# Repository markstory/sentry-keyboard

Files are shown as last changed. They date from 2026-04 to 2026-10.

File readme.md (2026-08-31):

# sentry-keyboard

A reverse engineered PCB for the keyboard that Sentry gave as holiday gift in 2024.

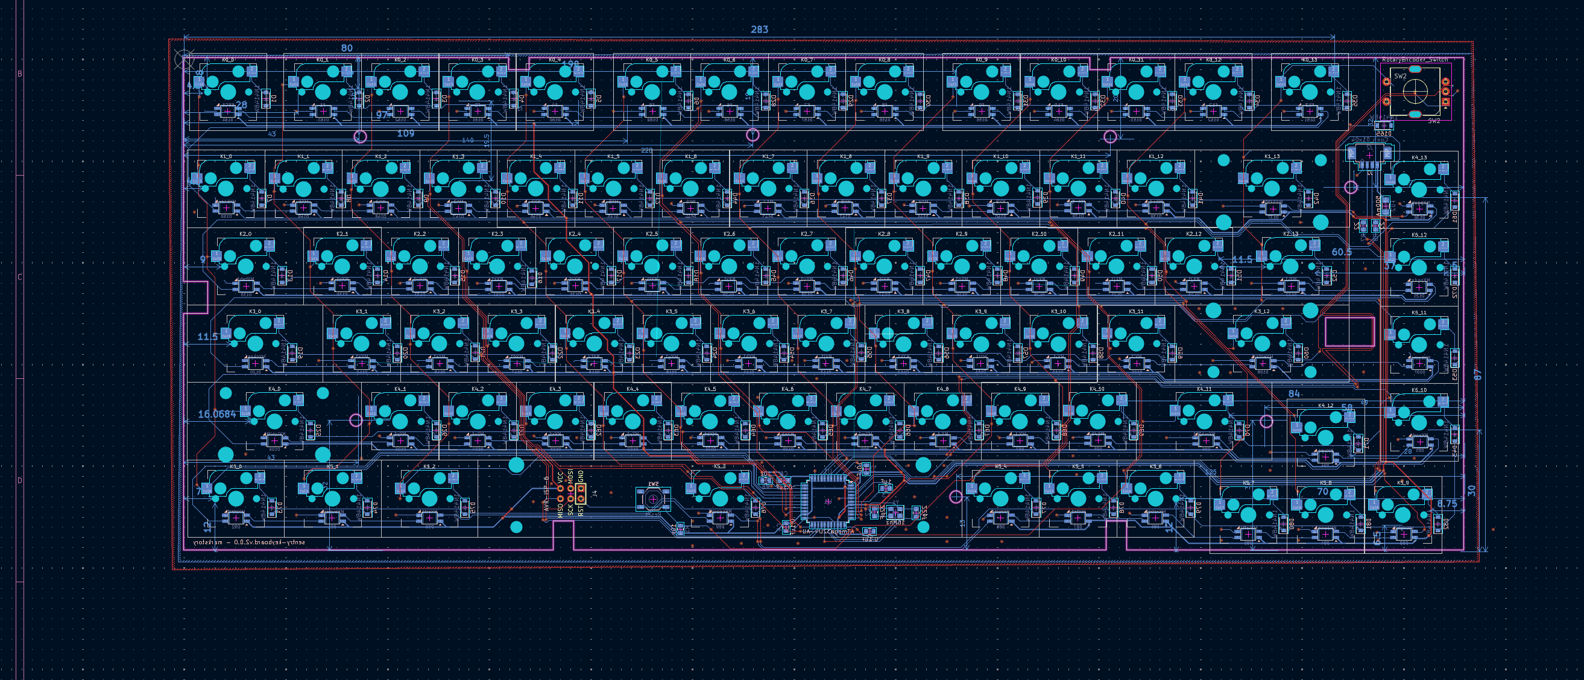
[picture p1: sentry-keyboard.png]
pcb screenshot


## Features

- Per key RGB LEDs
- Rotary encoder with switch
- USB host interface connection through picoblade connector.
- Programmable keymap with QMK

## Building the Firmware

The `firmware` directory of this repostiory contains only the files specific
to this keyboards firmware, and does not include all of QMK. To build firmware you
need to have a copy of QMK (lets assume it is at `~/code/qmk)`:

```bash
cp -R firmware/* ~/code/qmk/keyboards/sentry-keyboard
cd ~/code/qmk
qmk compile -kb sentry-keyboard -km default
```

This will compile a `.hex` file that you can flash onto your keyboard

```bash
qmk flash -kb sentry-keyboard
```

Brand new micro controller chips may have not have the bootloader initialized, 
and you'll need to erase the chip first:

```bash
dfu-programmer atmega32u4 erase
```

Once the chip has been erased you can flash the firmware on.

## License

Both the PCB design and firmware are provided under the MIT License

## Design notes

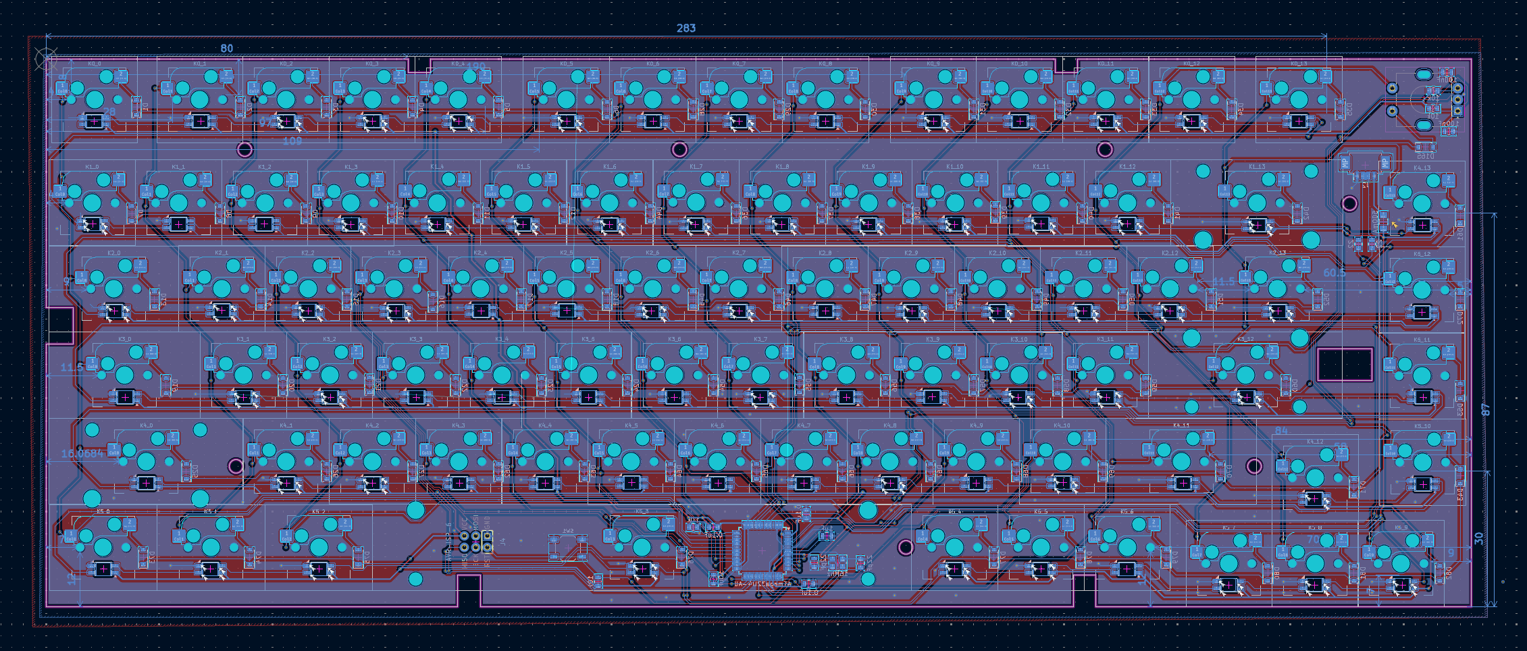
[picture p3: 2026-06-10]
board pcb with fills.png

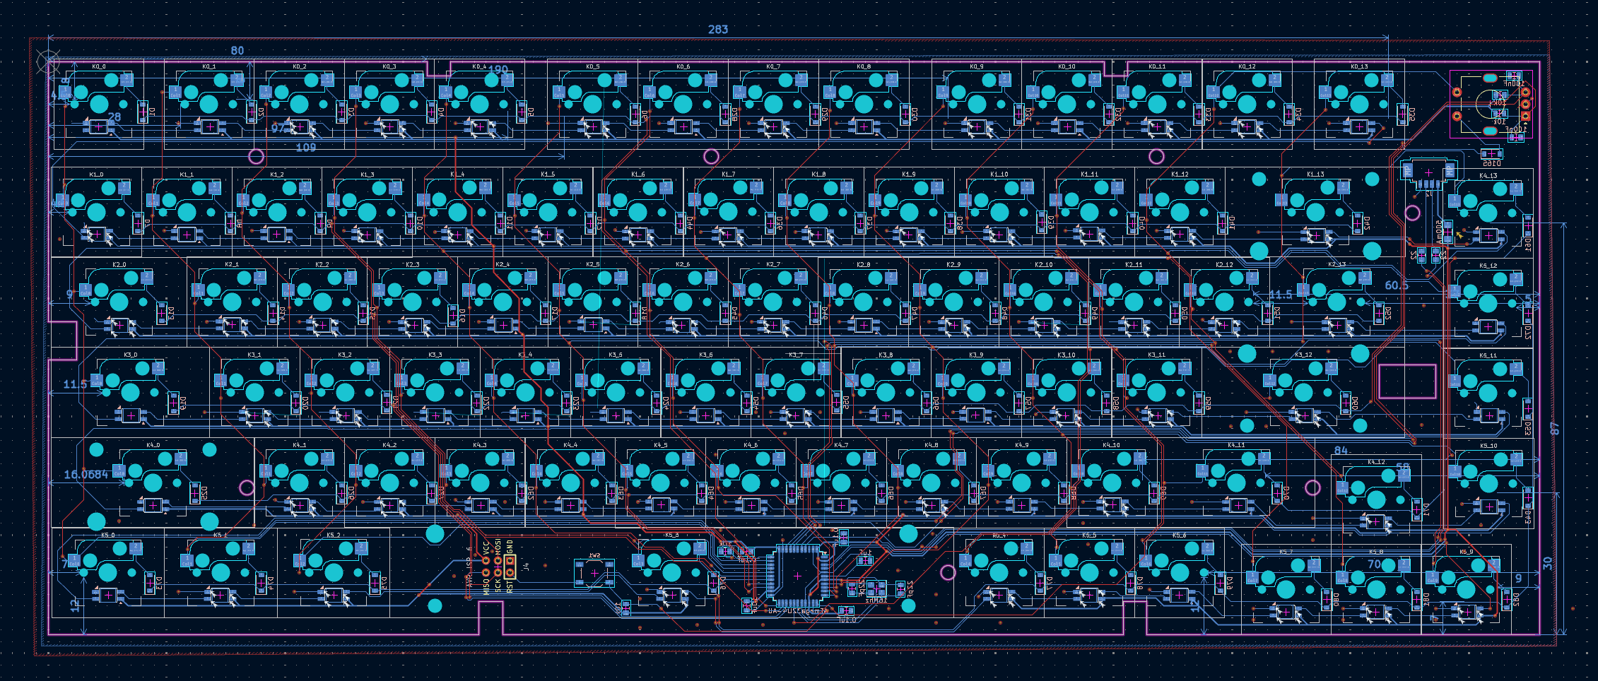
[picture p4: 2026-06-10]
board pcb no fills.png

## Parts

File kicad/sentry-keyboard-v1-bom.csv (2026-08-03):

Id | Designator | Footprint | Quantity | Designation | Supplier and ref
1 | J4 | Reset_Pretty-Mask | 1 | AVR-ISP-6
2 | SW2 | RotaryEncoder_EC11 | 1 | RotaryEncoder_Switch
3 | D62,D77,D46,D66,D32,D27,D79,D43,D65,D49,D42,D165,D64,D8,D61,D73,D81,D41,D69,D50,D1,D52,D34,D37,D14,D58,D76,D21,D45,D51,D31,D68,D2,D25,D10,D67,D30,D35,D23,D38,D6,D47,D9,D15,D57,D53,D59,D72,D11,D13,D12,D54,D80,D60,D28,D74,D16,D56,D17,D22,D33,D5,D24,D26,D48,D4,D44,D63,D3,D70,D40,D36,D78,D39,D20,D82,D7,D71,D18,D55,D19,D29,D75 | D_SOD-123 | 83 | 1N4148W
4 | D160,D126,D150,D96,D119,D147,D87,D109,D152,D105,D146,D110,D133,D85,D159,D88,D162,D90,D144,D134,D138,D84,D129,D132,D153,D83,D135,D145,D89,D141,D118,D108,D91,D104,D113,D137,D155,D98,D128,D157,D94,D151,D140,D107,D103,D149,D131,D114,D102,D148,D122,D116,D100,D115,D95,D86,D130,D111,D156,D120,D123,D93,D158,D117,D136,D106,D112,D161,D92,D101,D125,D164,D121,D139,D99,D124,D154,D143,D127,D142,D163,D97 | SK6812-MINI-E | 82 | SK6812
5 | C4,C6,C5 | C_0805_2012Metric | 3 | 0.1uF
6 | C7 | C_0805_2012Metric | 1 | 10uF
7 | MXr1 | MX-Hotswap-1U | 1 | K2_4
8 | MXx1 | MX-Hotswap-1U | 1 | K4_2
9 | MXlshift1 | MX-Hotswap-2.25U | 1 | K4_0
10 | MXend1 | MX-Hotswap-1U | 1 | K5_10
11 | MXspace1 | MX-Hotswap-6.25U-ReversedStabilizers | 1 | K5_3
12 | MXrshift1 | MX-Hotswap-1.75U | 1 | K4_11
13 | MX;1 | MX-Hotswap-1U | 1 | K3_10
14 | MX.1 | MX-Hotswap-1U | 1 | K4_9
15 | MXh1 | MX-Hotswap-1U | 1 | K3_6
16 | R1,R8 | R_0805_2012Metric | 2 | 10k
17 | C1,C2 | C_0805_2012Metric | 2 | 22pF
18 | C3 | C_0805_2012Metric | 1 | 1uF
19 | MXq1 | MX-Hotswap-1U | 1 | K2_1
20 | MX1 | MX-Hotswap-1U | 1 | K1_1
21 | MX\1 | MX-Hotswap-1.5U | 1 | K2_13
22 | MXbksp1 | MX-Hotswap-2U | 1 | K1_13
23 | MXa1 | MX-Hotswap-1U | 1 | K3_1
24 | MXb1 | MX-Hotswap-1U | 1 | K4_5
25 | MXj1 | MX-Hotswap-1U | 1 | K3_7
26 | SW1 | SW_SPST_TL3342 | 1 | Reset
27 | MX0 | MX-Hotswap-1U | 1 | K1_10
28 | F9 | MX-Hotswap-1U | 1 | K0_9
29 | MXhome1 | MX-Hotswap-1U | 1 | K5_11
30 | MXv1 | MX-Hotswap-1U | 1 | K4_4
31 | MXalt1 | MX-Hotswap-1.25U | 1 | K5_2
32 | MX4 | MX-Hotswap-1U | 1 | K1_4
33 | MXn1 | MX-Hotswap-1U | 1 | K4_6
34 | MX/1 | MX-Hotswap-1U | 1 | K4_10
35 | MXright1 | MX-Hotswap-1U | 1 | K5_9
36 | MXw1 | MX-Hotswap-1U | 1 | K2_2
37 | MXtilde1 | MX-Hotswap-1U | 1 | K1_0
38 | MXleft1 | MX-Hotswap-1U | 1 | K5_7
39 | U1 | TQFP-44_10x10mm_P0.8mm | 1 | ATmega32U4-AU
40 | F5 | MX-Hotswap-1U | 1 | K0_5
41 | MX5 | MX-Hotswap-1U | 1 | K1_5
42 | MXralt1 | MX-Hotswap-1U | 1 | K5_4
43 | MXup1 | MX-Hotswap-1U | 1 | K4_12
44 | MX3 | MX-Hotswap-1U | 1 | K1_3
45 | MXu1 | MX-Hotswap-1U | 1 | K2_7
46 | MXd1 | MX-Hotswap-1U | 1 | K3_3
47 | MXk1 | MX-Hotswap-1U | 1 | K3_8
48 | F7 | MX-Hotswap-1U | 1 | K0_7
49 | MXi1 | MX-Hotswap-1U | 1 | K2_8
50 | MXpgdn1 | MX-Hotswap-1U | 1 | K5_12
51 | F2 | MX-Hotswap-1U | 1 | K0_2
52 | MXpgup1 | MX-Hotswap-1U | 1 | K4_13
53 | F3 | MX-Hotswap-1U | 1 | K0_3
54 | R7,R6 | R_0805_2012Metric | 2 | 22
55 | MXg1 | MX-Hotswap-1U | 1 | K3_5
56 | MX2 | MX-Hotswap-1U | 1 | K1_2
57 | MXz1 | MX-Hotswap-1U | 1 | K4_1
58 | MXt1 | MX-Hotswap-1U | 1 | K2_5
59 | J2 | Molex_PicoBlade_53261-0471_1x04-1MP_P1.25mm_Horizontal | 1 | Conn_01x04
60 | MX'1 | MX-Hotswap-1U | 1 | K3_11
61 | F4 | MX-Hotswap-1U | 1 | K0_4
62 | F10 | MX-Hotswap-1U | 1 | K0_10
63 | MXrctrl1 | MX-Hotswap-1U | 1 | K5_6
64 | FU2 | Fuse_1206_3216Metric_Pad1.42x1.75mm_HandSolder | 1 | 500mA
65 | MXs1 | MX-Hotswap-1U | 1 | K3_2
66 | F12 | MX-Hotswap-1U | 1 | K0_12
67 | MX-1 | MX-Hotswap-1U | 1 | K1_11
68 | MX[1 | MX-Hotswap-1U | 1 | K2_11
69 | F6 | MX-Hotswap-1U | 1 | K0_6
70 | MXdown1 | MX-Hotswap-1U | 1 | K5_8
71 | MXl1 | MX-Hotswap-1U | 1 | K3_9
72 | F8 | MX-Hotswap-1U | 1 | K0_8
73 | MXfn1 | MX-Hotswap-1U | 1 | K5_5
74 | MX,1 | MX-Hotswap-1U | 1 | K4_8
75 | F11 | MX-Hotswap-1U | 1 | K0_11
76 | MXe1 | MX-Hotswap-1U | 1 | K2_3
77 | MXctrl1 | MX-Hotswap-1.25U | 1 | K5_0
78 | F1 | MX-Hotswap-1U | 1 | K0_1
79 | MXf2 | MX-Hotswap-1U | 1 | K3_4
80 | MXm1 | MX-Hotswap-1U | 1 | K4_7
81 | MX]1 | MX-Hotswap-1U | 1 | K2_12
82 | MXenter1 | MX-Hotswap-2.25U-ReversedStabilizers | 1 | K3_12
83 | MX+1 | MX-Hotswap-1U | 1 | K1_12
84 | MX9 | MX-Hotswap-1U | 1 | K1_9
85 | MXtab1 | MX-Hotswap-1.5U | 1 | K2_0
86 | MXy1 | MX-Hotswap-1U | 1 | K2_6
87 | MX8 | MX-Hotswap-1U | 1 | K1_8
88 | MXcaps1 | MX-Hotswap-1.75U | 1 | K3_0
89 | Y1 | Crystal_SMD_3225-4Pin_3.2x2.5mm | 1 | 16Mhz
90 | MXp1 | MX-Hotswap-1U | 1 | K2_10
91 | MXo1 | MX-Hotswap-1U | 1 | K2_9
92 | F13 | MX-Hotswap-1U | 1 | K0_13
93 | MXc1 | MX-Hotswap-1U | 1 | K4_3
94 | MX6 | MX-Hotswap-1U | 1 | K1_6
95 | MX7 | MX-Hotswap-1U | 1 | K1_7
96 | MXsuper1 | MX-Hotswap-1.25U | 1 | K5_1
97 | ESC1 | MX-Hotswap-1U | 1 | K0_0

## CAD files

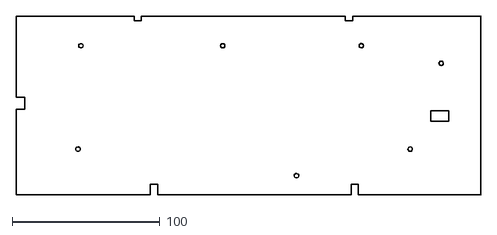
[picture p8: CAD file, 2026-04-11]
board outline.dxf
315.0 x 121.0

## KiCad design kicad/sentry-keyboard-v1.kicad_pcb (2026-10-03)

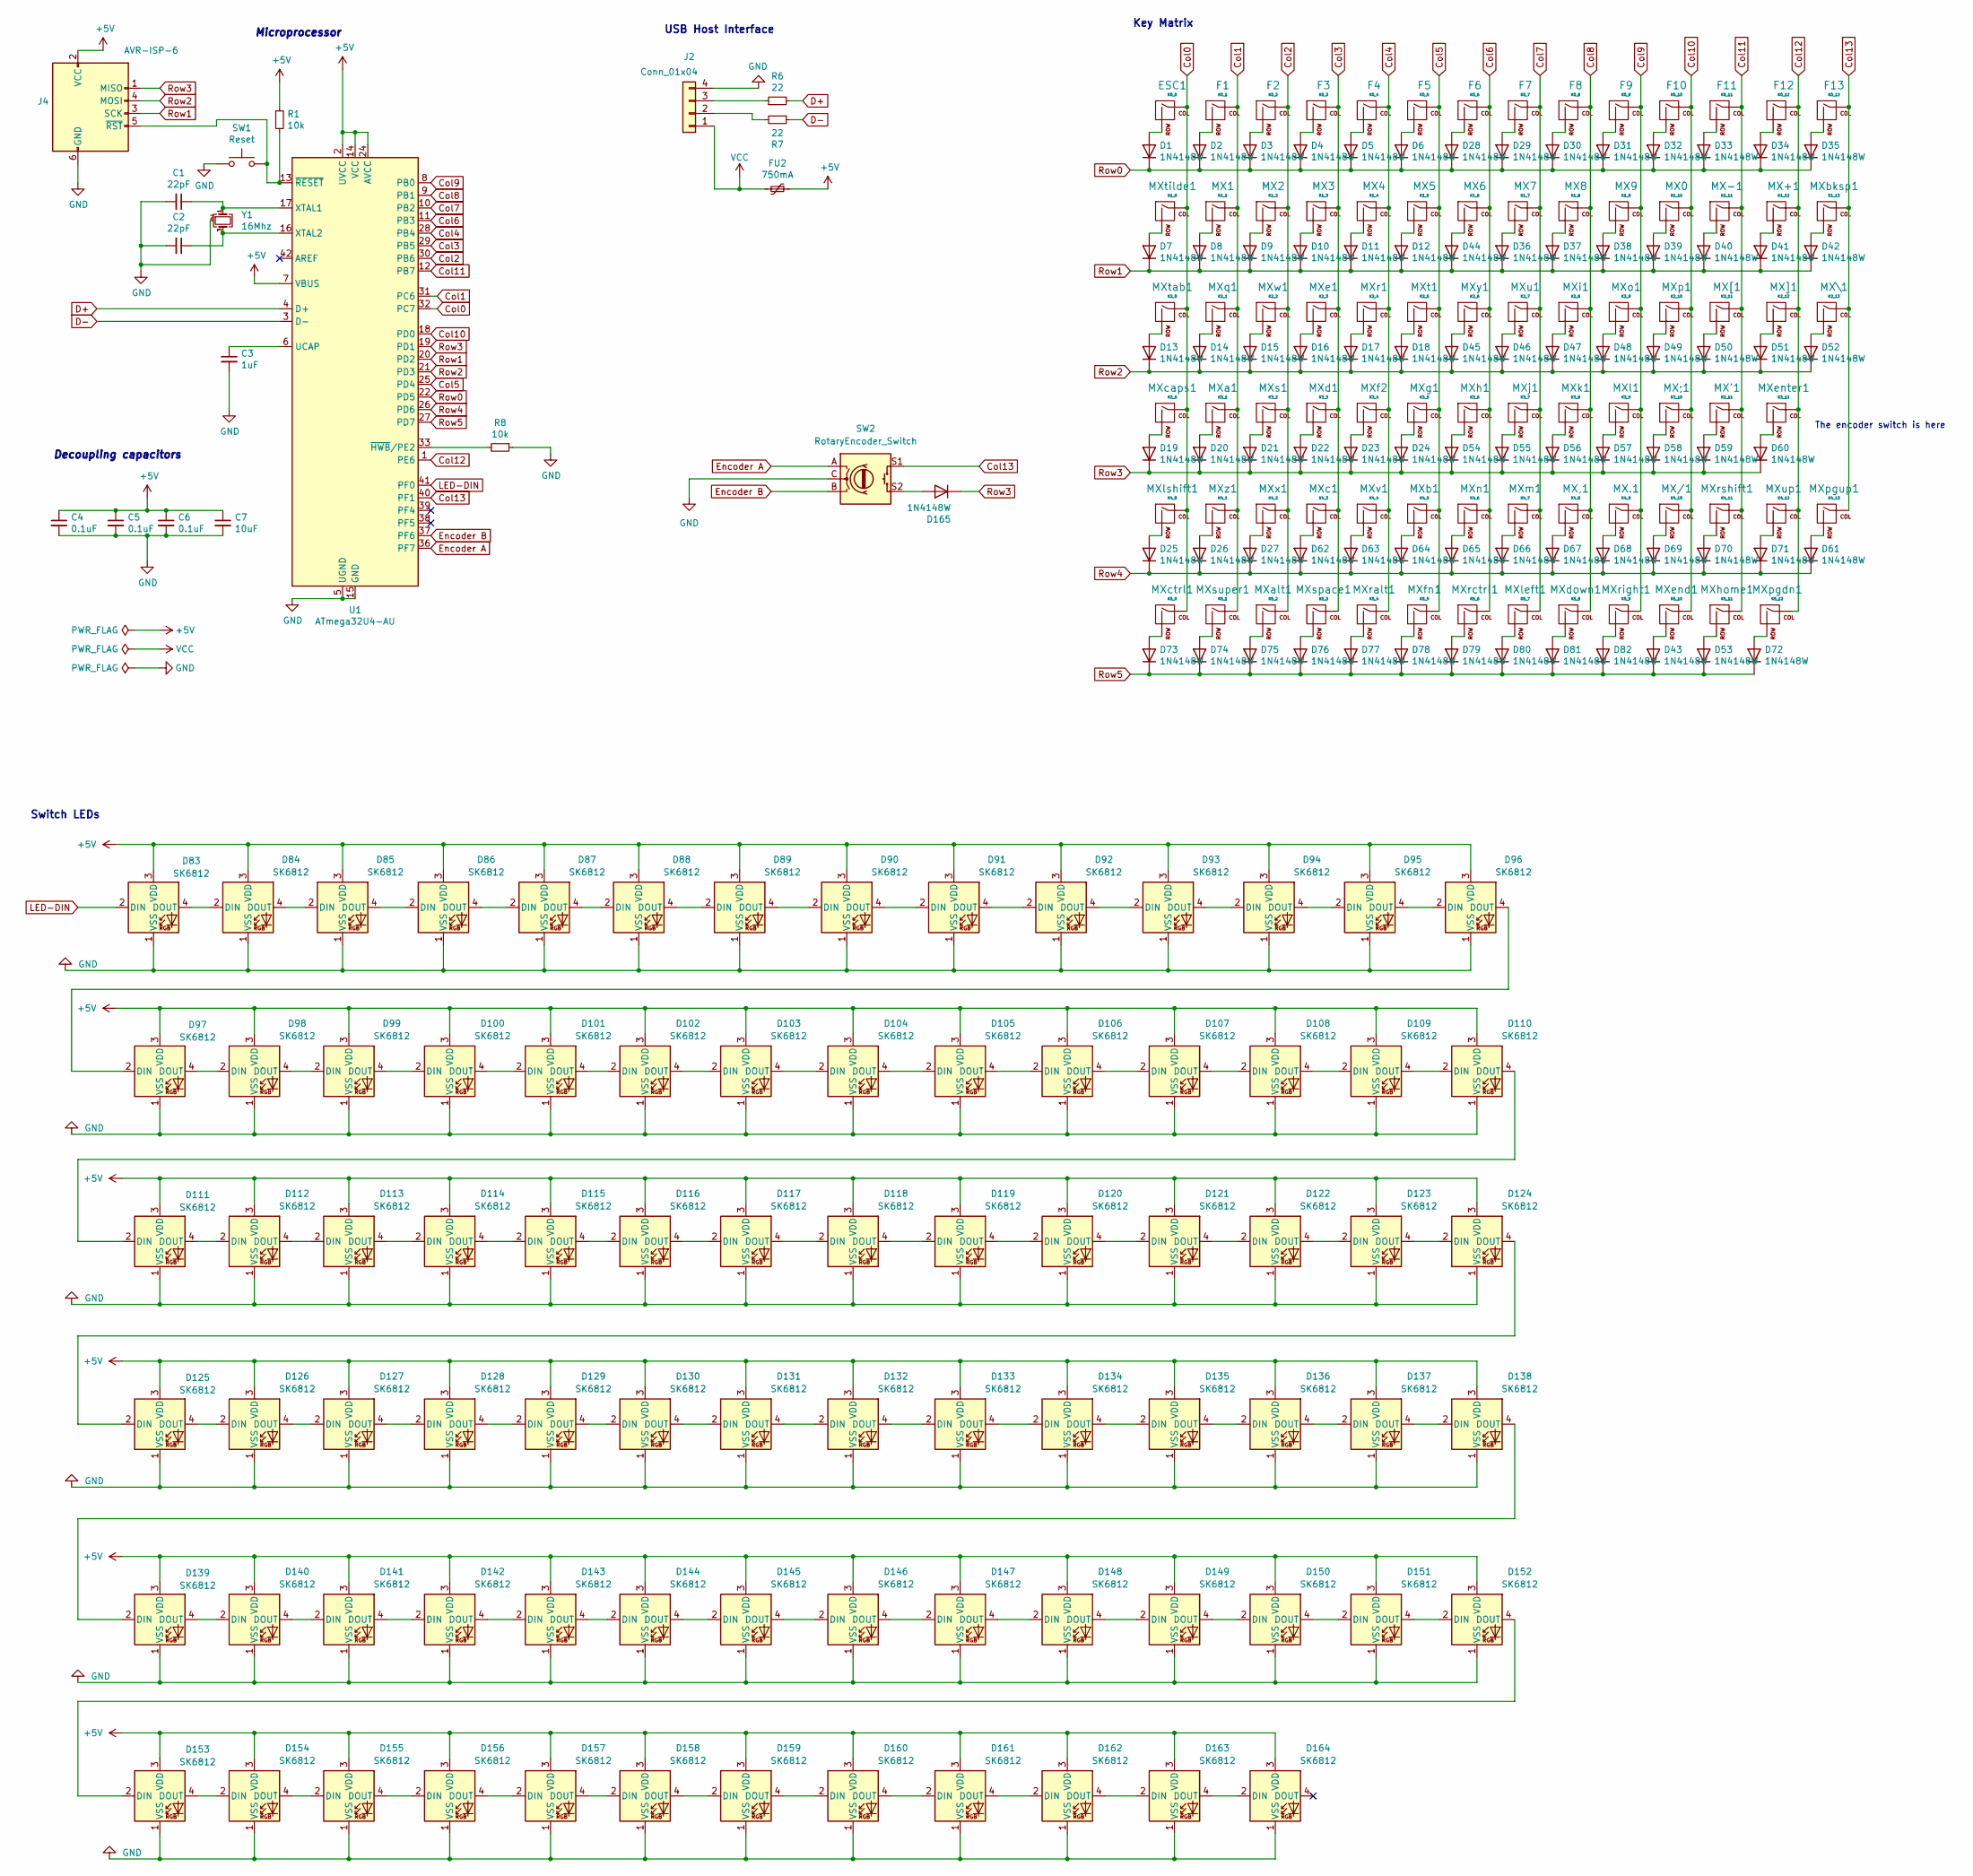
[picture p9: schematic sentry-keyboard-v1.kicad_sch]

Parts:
C1, C2: 22pF; C_0805_2012Metric
C3: 1uF; C_0805_2012Metric
C4, C5, C6: 0.1uF; C_0805_2012Metric
C7: 10uF; C_0805_2012Metric
D1, D2, D3, D4, D5, D6, D7, D8, D9, D10, D11, D12, D13, D14, D15, D16, D17, D18, D19, D20, D21, D22, D23, D24, D25, D26, D27, D28, D29, D30, D31, D32, D33, D34, D35, D36, D37, D38, D39, D40, D41, D42, D43, D44, D45, D46, D47, D48, D49, D50, D51, D52, D53, D54, D55, D56, D57, D58, D59, D60, D61, D62, D63, D64, D65, D66, D67, D68, D69, D70, D71, D72, D73, D74, D75, D76, D77, D78, D79, D80, D81, D82, D165: 1N4148W; D_SOD-123
D83, D84, D85, D86, D87, D88, D89, D90, D91, D92, D93, D94, D95, D96, D97, D98, D99, D100, D101, D102, D103, D104, D105, D106, D107, D108, D109, D110, D111, D112, D113, D114, D115, D116, D117, D118, D119, D120, D121, D122, D123, D124, D125, D126, D127, D128, D129, D130, D131, D132, D133, D134, D135, D136, D137, D138, D139, D140, D141, D142, D143, D144, D145, D146, D147, D148, D149, D150, D151, D152, D153, D154, D155, D156, D157, D158, D159, D160, D161, D162, D163, D164: SK6812; SK6812-MINI-E
ESC1: K0_0; MX-Hotswap-1U
F1: K0_1; MX-Hotswap-1U
F2: K0_2; MX-Hotswap-1U
F3: K0_3; MX-Hotswap-1U
F4: K0_4; MX-Hotswap-1U
F5: K0_5; MX-Hotswap-1U
F6: K0_6; MX-Hotswap-1U
F7: K0_7; MX-Hotswap-1U
F8: K0_8; MX-Hotswap-1U
F9: K0_9; MX-Hotswap-1U
F10: K0_10; MX-Hotswap-1U
F11: K0_11; MX-Hotswap-1U
F12: K0_12; MX-Hotswap-1U
F13: K0_13; MX-Hotswap-1U
FU2: 750mA; Fuse_1206_3216Metric_Pad1.42x1.75mm_HandSolder
J2: Conn_01x04; Molex_PicoBlade_53261-0471_1x04-1MP_P1.25mm_Horizontal
J4: AVR-ISP-6; Reset_Pretty-Mask
MX0: K1_10; MX-Hotswap-1U
MX1: K1_1; MX-Hotswap-1U
MX2: K1_2; MX-Hotswap-1U
MX3: K1_3; MX-Hotswap-1U
MX4: K1_4; MX-Hotswap-1U
MX5: K1_5; MX-Hotswap-1U
MX6: K1_6; MX-Hotswap-1U
MX7: K1_7; MX-Hotswap-1U
MX8: K1_8; MX-Hotswap-1U
MX9: K1_9; MX-Hotswap-1U
MX'1: K3_11; MX-Hotswap-1U
MX+1: K1_12; MX-Hotswap-1U
MX,1: K4_8; MX-Hotswap-1U
MX-1: K1_11; MX-Hotswap-1U
MX.1: K4_9; MX-Hotswap-1U
MX/1: K4_10; MX-Hotswap-1U
MX;1: K3_10; MX-Hotswap-1U
MX[1: K2_11; MX-Hotswap-1U
MX\1: K2_13; MX-Hotswap-1.5U
MX]1: K2_12; MX-Hotswap-1U
MXa1: K3_1; MX-Hotswap-1U
MXalt1: K5_2; MX-Hotswap-1.25U
MXb1: K4_5; MX-Hotswap-1U
MXbksp1: K1_13; MX-Hotswap-2U
MXc1: K4_3; MX-Hotswap-1U
MXcaps1: K3_0; MX-Hotswap-1.75U
MXctrl1: K5_0; MX-Hotswap-1.25U
MXd1: K3_3; MX-Hotswap-1U
MXdown1: K5_8; MX-Hotswap-1U
MXe1: K2_3; MX-Hotswap-1U
MXend1: K5_10; MX-Hotswap-1U
MXenter1: K3_12; MX-Hotswap-2.25U-ReversedStabilizers
MXf2: K3_4; MX-Hotswap-1U
MXfn1: K5_5; MX-Hotswap-1U
MXg1: K3_5; MX-Hotswap-1U
MXh1: K3_6; MX-Hotswap-1U
MXhome1: K5_11; MX-Hotswap-1U
MXi1: K2_8; MX-Hotswap-1U
MXj1: K3_7; MX-Hotswap-1U
MXk1: K3_8; MX-Hotswap-1U
MXl1: K3_9; MX-Hotswap-1U
MXleft1: K5_7; MX-Hotswap-1U
MXlshift1: K4_0; MX-Hotswap-2.25U
MXm1: K4_7; MX-Hotswap-1U
MXn1: K4_6; MX-Hotswap-1U
MXo1: K2_9; MX-Hotswap-1U
MXp1: K2_10; MX-Hotswap-1U
MXpgdn1: K5_12; MX-Hotswap-1U
MXpgup1: K4_13; MX-Hotswap-1U
MXq1: K2_1; MX-Hotswap-1U
MXr1: K2_4; MX-Hotswap-1U
MXralt1: K5_4; MX-Hotswap-1U
MXrctrl1: K5_6; MX-Hotswap-1U
MXright1: K5_9; MX-Hotswap-1U
MXrshift1: K4_11; MX-Hotswap-1.75U
MXs1: K3_2; MX-Hotswap-1U
MXspace1: K5_3; MX-Hotswap-6.25U-ReversedStabilizers
MXsuper1: K5_1; MX-Hotswap-1.25U
MXt1: K2_5; MX-Hotswap-1U
MXtab1: K2_0; MX-Hotswap-1.5U
MXtilde1: K1_0; MX-Hotswap-1U
MXu1: K2_7; MX-Hotswap-1U
MXup1: K4_12; MX-Hotswap-1U
MXv1: K4_4; MX-Hotswap-1U
MXw1: K2_2; MX-Hotswap-1U
MXx1: K4_2; MX-Hotswap-1U
MXy1: K2_6; MX-Hotswap-1U
MXz1: K4_1; MX-Hotswap-1U
R1, R8: 10k; R_0805_2012Metric
R6, R7: 22; R_0805_2012Metric
SW1: Reset; SW_SPST_TL3342
SW2: RotaryEncoder_Switch; RotaryEncoder_EC11
U1: ATmega32U4-AU; TQFP-44_10x10mm_P0.8mm
Y1: 16Mhz; Crystal_SMD_3225-4Pin_3.2x2.5mm

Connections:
+5V: C4.1, C5.1, C6.1, C7.1, D83.3 (VDD), D84.3 (VDD), D85.3 (VDD), D86.3 (VDD), D87.3 (VDD), D88.3 (VDD), D89.3 (VDD), D90.3 (VDD), D91.3 (VDD), D92.3 (VDD), D93.3 (VDD), D94.3 (VDD), D95.3 (VDD), D96.3 (VDD), D97.3 (VDD), D98.3 (VDD), D99.3 (VDD), D100.3 (VDD), D101.3 (VDD), D102.3 (VDD), D103.3 (VDD), D104.3 (VDD), D105.3 (VDD), D106.3 (VDD), D107.3 (VDD), D108.3 (VDD), D109.3 (VDD), D110.3 (VDD), D111.3 (VDD), D112.3 (VDD), D113.3 (VDD), D114.3 (VDD), D115.3 (VDD), D116.3 (VDD), D117.3 (VDD), D118.3 (VDD), D119.3 (VDD), D120.3 (VDD), D121.3 (VDD), D122.3 (VDD), D123.3 (VDD), D124.3 (VDD), D125.3 (VDD), D126.3 (VDD), D127.3 (VDD), D128.3 (VDD), D129.3 (VDD), D130.3 (VDD), D131.3 (VDD), D132.3 (VDD), D133.3 (VDD), D134.3 (VDD), D135.3 (VDD), D136.3 (VDD), D137.3 (VDD), D138.3 (VDD), D139.3 (VDD), D140.3 (VDD), D141.3 (VDD), D142.3 (VDD), D143.3 (VDD), D144.3 (VDD), D145.3 (VDD), D146.3 (VDD), D147.3 (VDD), D148.3 (VDD), D149.3 (VDD), D150.3 (VDD), D151.3 (VDD), D152.3 (VDD), D153.3 (VDD), D154.3 (VDD), D155.3 (VDD), D156.3 (VDD), D157.3 (VDD), D158.3 (VDD), D159.3 (VDD), D160.3 (VDD), D161.3 (VDD), D162.3 (VDD), D163.3 (VDD), D164.3 (VDD), FU2.1, J4.2 (VCC), R1.1, U1.2 (UVCC), U1.7 (VBUS), U1.14 (VCC), U1.24 (AVCC), U1.34 (VCC), U1.44 (AVCC)
Col0: ESC1.1 (COL), MXcaps1.1 (COL), MXctrl1.1 (COL), MXlshift1.1 (COL), MXtab1.1 (COL), MXtilde1.1 (COL), U1.32 (PC7)
Col1: F1.1 (COL), MX1.1 (COL), MXa1.1 (COL), MXq1.1 (COL), MXsuper1.1 (COL), MXz1.1 (COL), U1.31 (PC6)
Col2: F2.1 (COL), MX2.1 (COL), MXalt1.1 (COL), MXs1.1 (COL), MXw1.1 (COL), MXx1.1 (COL), U1.30 (PB6)
Col3: F3.1 (COL), MX3.1 (COL), MXc1.1 (COL), MXd1.1 (COL), MXe1.1 (COL), MXspace1.1 (COL), U1.29 (PB5)
Col4: F4.1 (COL), MX4.1 (COL), MXf2.1 (COL), MXr1.1 (COL), MXralt1.1 (COL), MXv1.1 (COL), U1.28 (PB4)
Col5: F5.1 (COL), MX5.1 (COL), MXb1.1 (COL), MXfn1.1 (COL), MXg1.1 (COL), MXt1.1 (COL), U1.25 (PD4)
Col6: F6.1 (COL), MX6.1 (COL), MXh1.1 (COL), MXn1.1 (COL), MXrctrl1.1 (COL), MXy1.1 (COL), U1.11 (PB3)
Col7: F7.1 (COL), MX7.1 (COL), MXj1.1 (COL), MXleft1.1 (COL), MXm1.1 (COL), MXu1.1 (COL), U1.10 (PB2)
Col8: F8.1 (COL), MX8.1 (COL), MX,1.1 (COL), MXdown1.1 (COL), MXi1.1 (COL), MXk1.1 (COL), U1.9 (PB1)
Col9: F9.1 (COL), MX9.1 (COL), MX.1.1 (COL), MXl1.1 (COL), MXo1.1 (COL), MXright1.1 (COL), U1.8 (PB0)
Col10: F10.1 (COL), MX0.1 (COL), MX/1.1 (COL), MX;1.1 (COL), MXend1.1 (COL), MXp1.1 (COL), U1.18 (PD0)
Col11: F11.1 (COL), MX'1.1 (COL), MX-1.1 (COL), MX[1.1 (COL), MXhome1.1 (COL), MXrshift1.1 (COL), U1.12 (PB7)
Col12: F12.1 (COL), MX+1.1 (COL), MX]1.1 (COL), MXenter1.1 (COL), MXpgdn1.1 (COL), MXup1.1 (COL), U1.1 (PE6)
Col13: F13.1 (COL), MX\1.1 (COL), MXbksp1.1 (COL), MXpgup1.1 (COL), SW2.S1, U1.40 (PF1)
D+: R6.2, U1.4 (D+)
D-: R7.1, U1.3 (D-)
Encoder A: SW2.A, U1.36 (PF7)
Encoder B: SW2.B, U1.37 (PF6)
GND: C1.2, C2.2, C3.2, C4.2, C5.2, C6.2, C7.2, D83.1 (VSS), D84.1 (VSS), D85.1 (VSS), D86.1 (VSS), D87.1 (VSS), D88.1 (VSS), D89.1 (VSS), D90.1 (VSS), D91.1 (VSS), D92.1 (VSS), D93.1 (VSS), D94.1 (VSS), D95.1 (VSS), D96.1 (VSS), D97.1 (VSS), D98.1 (VSS), D99.1 (VSS), D100.1 (VSS), D101.1 (VSS), D102.1 (VSS), D103.1 (VSS), D104.1 (VSS), D105.1 (VSS), D106.1 (VSS), D107.1 (VSS), D108.1 (VSS), D109.1 (VSS), D110.1 (VSS), D111.1 (VSS), D112.1 (VSS), D113.1 (VSS), D114.1 (VSS), D115.1 (VSS), D116.1 (VSS), D117.1 (VSS), D118.1 (VSS), D119.1 (VSS), D120.1 (VSS), D121.1 (VSS), D122.1 (VSS), D123.1 (VSS), D124.1 (VSS), D125.1 (VSS), D126.1 (VSS), D127.1 (VSS), D128.1 (VSS), D129.1 (VSS), D130.1 (VSS), D131.1 (VSS), D132.1 (VSS), D133.1 (VSS), D134.1 (VSS), D135.1 (VSS), D136.1 (VSS), D137.1 (VSS), D138.1 (VSS), D139.1 (VSS), D140.1 (VSS), D141.1 (VSS), D142.1 (VSS), D143.1 (VSS), D144.1 (VSS), D145.1 (VSS), D146.1 (VSS), D147.1 (VSS), D148.1 (VSS), D149.1 (VSS), D150.1 (VSS), D151.1 (VSS), D152.1 (VSS), D153.1 (VSS), D154.1 (VSS), D155.1 (VSS), D156.1 (VSS), D157.1 (VSS), D158.1 (VSS), D159.1 (VSS), D160.1 (VSS), D161.1 (VSS), D162.1 (VSS), D163.1 (VSS), D164.1 (VSS), J2.4, J4.6 (GND), R8.1, SW1.1, SW2.C, U1.5 (UGND), U1.15 (GND), U1.23 (GND), U1.35 (GND), U1.43 (GND), Y1.2 (G), Y1.4 (G)
LED-DIN: D83.2 (DIN), U1.41 (PF0)
unnamed: D1.2 (A), ESC1.2 (ROW)
unnamed: D2.2 (A), F1.2 (ROW)
unnamed: D3.2 (A), F2.2 (ROW)
unnamed: D4.2 (A), F3.2 (ROW)
unnamed: D5.2 (A), F4.2 (ROW)
unnamed: D6.2 (A), F5.2 (ROW)
unnamed: D7.2 (A), MXtilde1.2 (ROW)
unnamed: D8.2 (A), MX1.2 (ROW)
unnamed: D9.2 (A), MX2.2 (ROW)
unnamed: D10.2 (A), MX3.2 (ROW)
unnamed: D11.2 (A), MX4.2 (ROW)
unnamed: D12.2 (A), MX5.2 (ROW)
unnamed: D13.2 (A), MXtab1.2 (ROW)
unnamed: D14.2 (A), MXq1.2 (ROW)
unnamed: D15.2 (A), MXw1.2 (ROW)
unnamed: D16.2 (A), MXe1.2 (ROW)
unnamed: D17.2 (A), MXr1.2 (ROW)
unnamed: D18.2 (A), MXt1.2 (ROW)
unnamed: D19.2 (A), MXcaps1.2 (ROW)
unnamed: D20.2 (A), MXa1.2 (ROW)
unnamed: D21.2 (A), MXs1.2 (ROW)
unnamed: D22.2 (A), MXd1.2 (ROW)
unnamed: D23.2 (A), MXf2.2 (ROW)
unnamed: D24.2 (A), MXg1.2 (ROW)
unnamed: D25.2 (A), MXlshift1.2 (ROW)
unnamed: D26.2 (A), MXz1.2 (ROW)
unnamed: D27.2 (A), MXx1.2 (ROW)
unnamed: D28.2 (A), F6.2 (ROW)
unnamed: D29.2 (A), F7.2 (ROW)
unnamed: D30.2 (A), F8.2 (ROW)
unnamed: D31.2 (A), F9.2 (ROW)
unnamed: D32.2 (A), F10.2 (ROW)
unnamed: D33.2 (A), F11.2 (ROW)
unnamed: D34.2 (A), F12.2 (ROW)
unnamed: D35.2 (A), F13.2 (ROW)
unnamed: D36.2 (A), MX7.2 (ROW)
unnamed: D37.2 (A), MX8.2 (ROW)
unnamed: D38.2 (A), MX9.2 (ROW)
unnamed: D39.2 (A), MX0.2 (ROW)
unnamed: D40.2 (A), MX-1.2 (ROW)
unnamed: D41.2 (A), MX+1.2 (ROW)
unnamed: D42.2 (A), MXbksp1.2 (ROW)
unnamed: D43.2 (A), MXend1.2 (ROW)
unnamed: D44.2 (A), MX6.2 (ROW)
unnamed: D45.2 (A), MXy1.2 (ROW)
unnamed: D46.2 (A), MXu1.2 (ROW)
unnamed: D47.2 (A), MXi1.2 (ROW)
unnamed: D48.2 (A), MXo1.2 (ROW)
unnamed: D49.2 (A), MXp1.2 (ROW)
unnamed: D50.2 (A), MX[1.2 (ROW)
unnamed: D51.2 (A), MX]1.2 (ROW)
unnamed: D52.2 (A), MX\1.2 (ROW)
unnamed: D53.2 (A), MXhome1.2 (ROW)
unnamed: D54.2 (A), MXh1.2 (ROW)
unnamed: D55.2 (A), MXj1.2 (ROW)
unnamed: D56.2 (A), MXk1.2 (ROW)
unnamed: D57.2 (A), MXl1.2 (ROW)
unnamed: D58.2 (A), MX;1.2 (ROW)
unnamed: D59.2 (A), MX'1.2 (ROW)
unnamed: D60.2 (A), MXenter1.2 (ROW)
unnamed: D61.2 (A), MXpgup1.2 (ROW)
unnamed: D62.2 (A), MXc1.2 (ROW)
unnamed: D63.2 (A), MXv1.2 (ROW)
unnamed: D64.2 (A), MXb1.2 (ROW)
unnamed: D65.2 (A), MXn1.2 (ROW)
unnamed: D66.2 (A), MXm1.2 (ROW)
unnamed: D67.2 (A), MX,1.2 (ROW)
unnamed: D68.2 (A), MX.1.2 (ROW)
unnamed: D69.2 (A), MX/1.2 (ROW)
unnamed: D70.2 (A), MXrshift1.2 (ROW)
unnamed: D71.2 (A), MXup1.2 (ROW)
unnamed: D72.2 (A), MXpgdn1.2 (ROW)
unnamed: D73.2 (A), MXctrl1.2 (ROW)
unnamed: D74.2 (A), MXsuper1.2 (ROW)
unnamed: D75.2 (A), MXalt1.2 (ROW)
unnamed: D76.2 (A), MXspace1.2 (ROW)
unnamed: D77.2 (A), MXralt1.2 (ROW)
unnamed: D78.2 (A), MXfn1.2 (ROW)
unnamed: D79.2 (A), MXrctrl1.2 (ROW)
unnamed: D80.2 (A), MXleft1.2 (ROW)
unnamed: D81.2 (A), MXdown1.2 (ROW)
unnamed: D82.2 (A), MXright1.2 (ROW)
unnamed: D83.4 (DOUT), D84.2 (DIN)
unnamed: D84.4 (DOUT), D85.2 (DIN)
unnamed: D85.4 (DOUT), D86.2 (DIN)
unnamed: D86.4 (DOUT), D87.2 (DIN)
unnamed: D87.4 (DOUT), D88.2 (DIN)
unnamed: D88.4 (DOUT), D89.2 (DIN)
unnamed: D89.4 (DOUT), D90.2 (DIN)
unnamed: D90.4 (DOUT), D91.2 (DIN)
unnamed: D91.4 (DOUT), D92.2 (DIN)
unnamed: D92.4 (DOUT), D93.2 (DIN)
unnamed: D93.4 (DOUT), D94.2 (DIN)
unnamed: D94.4 (DOUT), D95.2 (DIN)
unnamed: D95.4 (DOUT), D96.2 (DIN)
unnamed: D96.4 (DOUT), D97.2 (DIN)
unnamed: D97.4 (DOUT), D98.2 (DIN)
unnamed: D98.4 (DOUT), D99.2 (DIN)
unnamed: D99.4 (DOUT), D100.2 (DIN)
unnamed: D100.4 (DOUT), D101.2 (DIN)
unnamed: D101.4 (DOUT), D102.2 (DIN)
unnamed: D102.4 (DOUT), D103.2 (DIN)
unnamed: D103.4 (DOUT), D104.2 (DIN)
unnamed: D104.4 (DOUT), D105.2 (DIN)
unnamed: D105.4 (DOUT), D106.2 (DIN)
unnamed: D106.4 (DOUT), D107.2 (DIN)
unnamed: D107.4 (DOUT), D108.2 (DIN)
unnamed: D108.4 (DOUT), D109.2 (DIN)
unnamed: D109.4 (DOUT), D110.2 (DIN)
unnamed: D110.4 (DOUT), D111.2 (DIN)
unnamed: D111.4 (DOUT), D112.2 (DIN)
unnamed: D112.4 (DOUT), D113.2 (DIN)
unnamed: D113.4 (DOUT), D114.2 (DIN)
unnamed: D114.4 (DOUT), D115.2 (DIN)
unnamed: D115.4 (DOUT), D116.2 (DIN)
unnamed: D116.4 (DOUT), D117.2 (DIN)
unnamed: D117.4 (DOUT), D118.2 (DIN)
unnamed: D118.4 (DOUT), D119.2 (DIN)
unnamed: D119.4 (DOUT), D120.2 (DIN)
unnamed: D120.4 (DOUT), D121.2 (DIN)
unnamed: D121.4 (DOUT), D122.2 (DIN)
unnamed: D122.4 (DOUT), D123.2 (DIN)
unnamed: D123.4 (DOUT), D124.2 (DIN)
unnamed: D124.4 (DOUT), D125.2 (DIN)
unnamed: D125.4 (DOUT), D126.2 (DIN)
unnamed: D126.4 (DOUT), D127.2 (DIN)
unnamed: D127.4 (DOUT), D128.2 (DIN)
unnamed: D128.4 (DOUT), D129.2 (DIN)
unnamed: D129.4 (DOUT), D130.2 (DIN)
unnamed: D130.4 (DOUT), D131.2 (DIN)
unnamed: D131.4 (DOUT), D132.2 (DIN)
unnamed: D132.4 (DOUT), D133.2 (DIN)
unnamed: D133.4 (DOUT), D134.2 (DIN)
unnamed: D134.4 (DOUT), D135.2 (DIN)
unnamed: D135.4 (DOUT), D136.2 (DIN)
unnamed: D136.4 (DOUT), D137.2 (DIN)
unnamed: D137.4 (DOUT), D138.2 (DIN)
unnamed: D138.4 (DOUT), D139.2 (DIN)
unnamed: D139.4 (DOUT), D140.2 (DIN)
unnamed: D140.4 (DOUT), D141.2 (DIN)
unnamed: D141.4 (DOUT), D142.2 (DIN)
unnamed: D142.4 (DOUT), D143.2 (DIN)
unnamed: D143.4 (DOUT), D144.2 (DIN)
unnamed: D144.4 (DOUT), D145.2 (DIN)
unnamed: D145.4 (DOUT), D146.2 (DIN)
unnamed: D146.4 (DOUT), D147.2 (DIN)
unnamed: D147.4 (DOUT), D148.2 (DIN)
unnamed: D148.4 (DOUT), D149.2 (DIN)
unnamed: D149.4 (DOUT), D150.2 (DIN)
unnamed: D150.4 (DOUT), D151.2 (DIN)
unnamed: D151.4 (DOUT), D152.2 (DIN)
unnamed: D152.4 (DOUT), D153.2 (DIN)
unnamed: D153.4 (DOUT), D154.2 (DIN)
unnamed: D154.4 (DOUT), D155.2 (DIN)
unnamed: D155.4 (DOUT), D156.2 (DIN)
unnamed: D156.4 (DOUT), D157.2 (DIN)
unnamed: D157.4 (DOUT), D158.2 (DIN)
unnamed: D158.4 (DOUT), D159.2 (DIN)
unnamed: D159.4 (DOUT), D160.2 (DIN)
unnamed: D160.4 (DOUT), D161.2 (DIN)
unnamed: D161.4 (DOUT), D162.2 (DIN)
unnamed: D162.4 (DOUT), D163.2 (DIN)
unnamed: D163.4 (DOUT), D164.2 (DIN)
unnamed: D165.2 (A), SW2.S2
unnamed: J2.2, R7.2
unnamed: J2.3, R6.1
unnamed: J4.5 (~RST), R1.2, SW1.2, U1.13 (~RESET)
unnamed: C3.1, U1.6 (UCAP)
unnamed: C1.1, U1.17 (XTAL1), Y1.1
unnamed: C2.1, U1.16 (XTAL2), Y1.3
unnamed: R8.2, U1.33 (~HWB/PE2)
Row0: D1.1 (K), D2.1 (K), D3.1 (K), D4.1 (K), D5.1 (K), D6.1 (K), D28.1 (K), D29.1 (K), D30.1 (K), D31.1 (K), D32.1 (K), D33.1 (K), D34.1 (K), D35.1 (K), U1.22 (PD5)
Row1: D7.1 (K), D8.1 (K), D9.1 (K), D10.1 (K), D11.1 (K), D12.1 (K), D36.1 (K), D37.1 (K), D38.1 (K), D39.1 (K), D40.1 (K), D41.1 (K), D42.1 (K), D44.1 (K), J4.3 (SCK), U1.20 (PD2)
Row2: D13.1 (K), D14.1 (K), D15.1 (K), D16.1 (K), D17.1 (K), D18.1 (K), D45.1 (K), D46.1 (K), D47.1 (K), D48.1 (K), D49.1 (K), D50.1 (K), D51.1 (K), D52.1 (K), J4.4 (MOSI), U1.21 (PD3)
Row3: D19.1 (K), D20.1 (K), D21.1 (K), D22.1 (K), D23.1 (K), D24.1 (K), D54.1 (K), D55.1 (K), D56.1 (K), D57.1 (K), D58.1 (K), D59.1 (K), D60.1 (K), D165.1 (K), J4.1 (MISO), U1.19 (PD1)
Row4: D25.1 (K), D26.1 (K), D27.1 (K), D61.1 (K), D62.1 (K), D63.1 (K), D64.1 (K), D65.1 (K), D66.1 (K), D67.1 (K), D68.1 (K), D69.1 (K), D70.1 (K), D71.1 (K), U1.26 (PD6)
Row5: D43.1 (K), D53.1 (K), D72.1 (K), D73.1 (K), D74.1 (K), D75.1 (K), D76.1 (K), D77.1 (K), D78.1 (K), D79.1 (K), D80.1 (K), D81.1 (K), D82.1 (K), U1.27 (PD7)
VCC: FU2.2, J2.1

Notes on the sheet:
Switch LEDs
USB Host Interface
Microprocessor
Decoupling capacitors
The encoder switch is here
Key Matrix

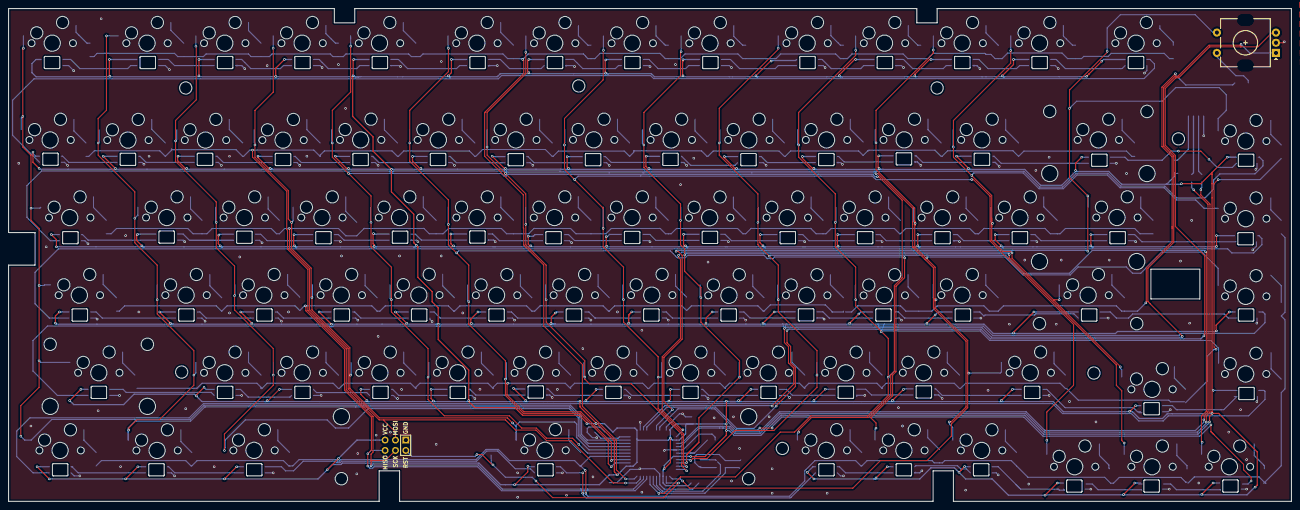
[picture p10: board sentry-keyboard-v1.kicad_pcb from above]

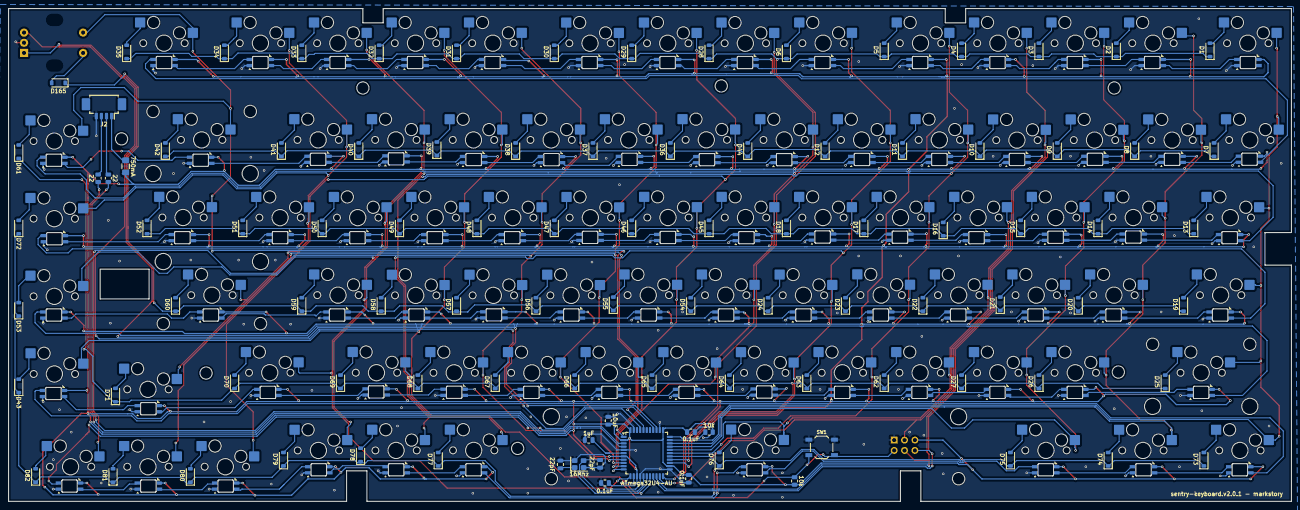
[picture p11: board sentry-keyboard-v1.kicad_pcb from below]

Board: 2 copper layers, 315.0 x 121.0 mm, 265 parts (263 on the bottom side), 199 nets.

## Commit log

2026-04-04 Import MCU, host USB from ursaminor
    - Add LED and encoder nets
    - Make switch matrix the correct size.
    [sentry-keyboard-v1.kicad_pcb, sentry-keyboard-v1.kicad_sch]
2026-04-04 Add first draft of LED matrix
    Need to figure out if each LED needs a 100uf capacitor, and if the data
    line needs a resistor still. The datasheet is really hard to read
    because of low quality scan.
    [sentry-keyboard-v1.kicad_sch]
2026-04-10 Update schematic
    - Label all the keys to make sure I have them all
    - Reroute a few keys so that routing will be easier
    - Wire up the switch on the encoder
    [sentry-keyboard-v1.kicad_sch]
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2026-04-16 Update schematic
    - fix avr isp pin out
    - add footprints to switches and leds
    [sentry-keyboard-v1.kicad_sch]
2026-04-18 Add another footprint library for switches and hotswaps
    [Gateron-KS33-Socket.step, Kailh-Choc-Socket-CPG135001S30.step, MX-Hotswap-Socket.step]
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2026-04-18 Cleanup rotary encoder wiring
    - forgot a diode
    - don't need as many resistors. I looked at a couple other keyboards
    with rotary encoders and none of them had two sets of resistors.
    [sentry-keyboard-v1.kicad_sch]
2026-04-18 Fix footprint
    [sentry-keyboard-v1.kicad_sch]
2026-04-18 Add Mx_Alps_Hybrid library to get schematic symbols back
    [sentry-keyboard-v1.kicad_sch]
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2026-05-01 Place more footprints.
    Now I have to do a lot of measuring and get all the keyswitch locations
    dialed in.
    [sentry-keyboard-v1.kicad_pcb, sentry-keyboard-v1.kicad_sch]
2026-05-02 Rough place more componentso
    - Keys are mostly in the right place. I need to confirm the size of
    a few caps and then do fine measurements.
    - Placing the ribbon LEDs in a snake pattern. This will make routing
    easier but could complicate the firmware mapping.
    [sentry-keyboard-v1.kicad_pcb]
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2026-05-06 Dial in positions of a few keys and change the footprint of the usb connection.
    I need to find out what the keyboard's daughter card has on it, as this
    could be simpler to build.
    [sentry-keyboard-v1.kicad_pcb, sentry-keyboard-v1.kicad_sch]
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2026-05-09 Fix up
    [sentry-keyboard-v1.kicad_pcb]
2026-05-09 Get row 4 placed.
    Had to change the size of several switches as they were wrong.
    [sentry-keyboard-v1.kicad_pcb, sentry-keyboard-v1.kicad_sch]
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2026-05-10 Place row 1
    Fix \ footprint as it looks like 1.5u is the right size. I have to
    remeasure to be sure.
    [sentry-keyboard-v1.kicad_pcb, sentry-keyboard-v1.kicad_sch]
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2026-05-11 Simpler USB connection
    The keyboard case comes with a USBC breakout card. This card contains
    the 5.1K resistors, and what looks like an ESD on them. I've removed
    those from the schematics, and assigned a picoblade connector, as that
    is what I think the board is currently using.
    [sentry-keyboard-v1.kicad_pcb, sentry-keyboard-v1.kicad_sch]
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2026-05-14 Fix silkscreen
    [sentry-keyboard-v1.kicad_pcb]
2026-05-18 Fix a bunch of alignment issues.
    [sentry-keyboard-v1.kicad_pcb]
2026-05-18 Update footprints and adjust positioning
    I printed out the schematic and compare with the physical board and
    needed to make some adjustments.
    [sentry-keyboard-v1.kicad_pcb, sentry-keyboard-v1.kicad_sch]
2026-05-18 Move measures to user comments and start traces
    [sentry-keyboard-v1.kicad_pcb]
2026-05-20 Fix a big schematic mistake
    I had two col5 nets! I only noticed this as I started routing the
    columns. I also fixed the numbering of all the switches.
    [sentry-keyboard-v1.kicad_pcb, sentry-keyboard-v1.kicad_sch]
2026-05-20 Route more columns
    The cpu area needs to be reworked once all the columns are roughed in.
    [sentry-keyboard-v1.kicad_pcb]
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2026-05-24 Route a few LEDs
    Get a few complete keys together to better understand how the layout
    will work.
    [sentry-keyboard-v1.kicad_pcb]
2026-05-24 Move diodes up so that wiring LEDs is and diodes is easier.
    [sentry-keyboard-v1.kicad_pcb]
2026-05-25 Route part of row 1
    This was so much easier. I need to replace all the LEDS on Rows 0, 2, 4
    as the LEDS are much simpler to route going left to right. I'll have go
    figure out the signal loop back at the end of each row.
    [sentry-keyboard-v1.kicad_pcb]
2026-05-28 Reposition all the LEDs so that routing isn't unhinged
    [sentry-keyboard-v1.kicad_pcb]
2026-05-28 Position the LEDS more tightly
    [sentry-keyboard-v1.kicad_pcb]
2026-05-28 Route the LEDs and make progress on the switch matrix
    [sentry-keyboard-v1.kicad_pcb]
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2026-06-03 Add led switch backs.
    hopefully the distance doesn't matter too much
    [sentry-keyboard-v1.kicad_pcb]
2026-06-05 Start connecting up the mcu
    reassign a bunch of pins to make routing easier.
    [sentry-keyboard-v1.kicad_pcb, sentry-keyboard-v1.kicad_sch]
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2026-06-07 Rough routing is complete
    Still lots of small tweaks and clean up to do.
    [sentry-keyboard-v1.kicad_pcb, sentry-keyboard-v1.kicad_sch]
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2026-06-09 Run cleanup and start resovling DRC errors.
    [sentry-keyboard-v1.kicad_pcb]
2026-06-10 Fix a pile of DRC errors
    Still quite a few to go sadly
    [sentry-keyboard-v1.kicad_pcb]
2026-06-10 Got DRC passing.
    - Improved back silkscreen to make it easier to assemble as a novice.
    [sentry-keyboard-v1.kicad_pcb]
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2026-06-14 Tested in paper again with switch plate.
    Need to adjust a few holes. Still have to move the rotary encoder.
    [sentry-keyboard-v1.kicad_pcb]
2026-06-14 Adjust position of holes and encoder
    After a paper test these elements needed repositioning
    [sentry-keyboard-v1.kicad_pcb]
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2026-06-24 Closer to firmware that might work
    - Get pins updated
    - Cleanup matrix to align with schematic
    - I've completely hosed the visual layout. I need to fix this.
2026-06-28 Fix ordering of home/end
    [sentry-keyboard-v1.kicad_pcb, sentry-keyboard-v1.kicad_sch]
2026-06-28 Update pins for encoder
    I had the encoder and a switch on the same row/col
    [sentry-keyboard-v1.kicad_pcb, sentry-keyboard-v1.kicad_sch]
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2026-07-02 Update pins and fix routing
    [sentry-keyboard-v1.kicad_pcb, sentry-keyboard-v1.kicad_sch]
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2026-07-05 Simplify encoder wiring
    I built a prototype on a breadboard and the resistors and caps are not
    required.
    [sentry-keyboard-v1.kicad_sch]
2026-07-05 Revise routing for simpler encoder
    Redo routing around the encoder as it is simpler now.
    [sentry-keyboard-v1.kicad_pcb]
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2026-07-12 Generate parts list from kicad
    This will need some work.
    [sentry-keyboard-v1.csv]
2026-07-22 Adjust positioning of several footprints
    After testing with a paper prototype some footprints need to move.
    [sentry-keyboard-v1.kicad_pcb]
2026-07-23 Another round of positioning tweaks
    f keys are still way off. Board outline moved to line up better with the
    switchplate foam.
    [sentry-keyboard-v1.kicad_pcb]
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2026-07-26 Fix routing on row0
    [sentry-keyboard-v1.kicad_pcb]
2026-07-26 Fix DRC errors
    [sentry-keyboard-v1.kicad_pcb]
2026-08-03 Flipped pins on USB connection
    I had measured the pins on the daughter card, but the pins are reversed
    on the mainboard.
    [sentry-keyboard-v1.kicad_pcb, sentry-keyboard-v1.kicad_sch]
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2026-09-03 Fix pin matrix
    Had a few columns/rows not working because the pins were wrong.
2026-09-03 I mixed up VSS and VDD
    When connecting the LEDs in the schematic I flipped VSS (gnd) and VDD
    (5v). The LED matrix won't work in the current wiring and needs to be
    rerouted entirely.
    Update routing for the first row.
    [sentry-keyboard-v1.kicad_pcb, sentry-keyboard-v1.kicad_sch]
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2026-09-04 Fix row0 LEDs and fill in ground plane
    [sentry-keyboard-v1.kicad_pcb]
2026-09-06 Cleanup traces and bump hardware rev
    The 2.0.0 revision has bad LED circuits, and is tight in the keyboard
    case. This revision has correct LED circuits and more space where the
    keyboard fits around case hardware
    [sentry-keyboard-v1.kicad_pcb]
2026-09-06 More DRC fixes
    [sentry-keyboard-v1.kicad_pcb]
2026-09-07 Add/check more measurements.
    - Make the hole on the right side 0.25mm taller.
    - Move the rotary encoder 0.25mm to the right.
    [sentry-keyboard-v1.kicad_pcb]
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2026-10-03 Use a bigger fuse
    500mA was popping when all the LEDs were connected at default
    brightness. This took a long time to figure out sadly.
    [sentry-keyboard-v1.kicad_pcb, sentry-keyboard-v1.kicad_sch]
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2026-10-27 Move reset button
    Move the reset button to align with the case hole.
    I missed this earlier as I never did any test fits with the bottom case.
